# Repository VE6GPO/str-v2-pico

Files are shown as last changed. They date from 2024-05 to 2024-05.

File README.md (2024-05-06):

# Controlling NJW1194 pre-amp with RasPi Pico or Arduino Nano

### NJW1194 has:
- 4 stereo inputs
- SPI interface
- Volume control (separate L/R)
- Tone controls (Bass/Treble)

## Requirements:

### Audio inputs:
- AM Radio
- FM Radio
- IP Radio (Raspberry Pi as an internet radio stream receiver)
- External input (TV)

### MCU inputs - total 12 GPI:
- Power switch - 1 GPI
- Phono/AM/FM switch - 3 GPI
- Tape Select - 1 GPI
- Volume (rotary ctrl) - 2 GPI
- Mute - 1 GPI
- Bass/Treble/Balance - 3 ADC
- IR receiver - 1 GPI

### MCU outputs - total 9 GPO:
- Power relay - 1 GPO
- SPI (Data, Clock, ChipSelect) - 3 GPO
- RGB dial light (PWM) - 3 GPO
- Display I2C - 2 GPO

MCU needs 21 GPIO lines in total, plus maybe another 2 to "talk" to Raspberry Pi ...

### TODO:

- Utilize rotary encoder w. push button for Volume/Mute control
- Use existing pots fed to ADC for controlling Tone + Balance

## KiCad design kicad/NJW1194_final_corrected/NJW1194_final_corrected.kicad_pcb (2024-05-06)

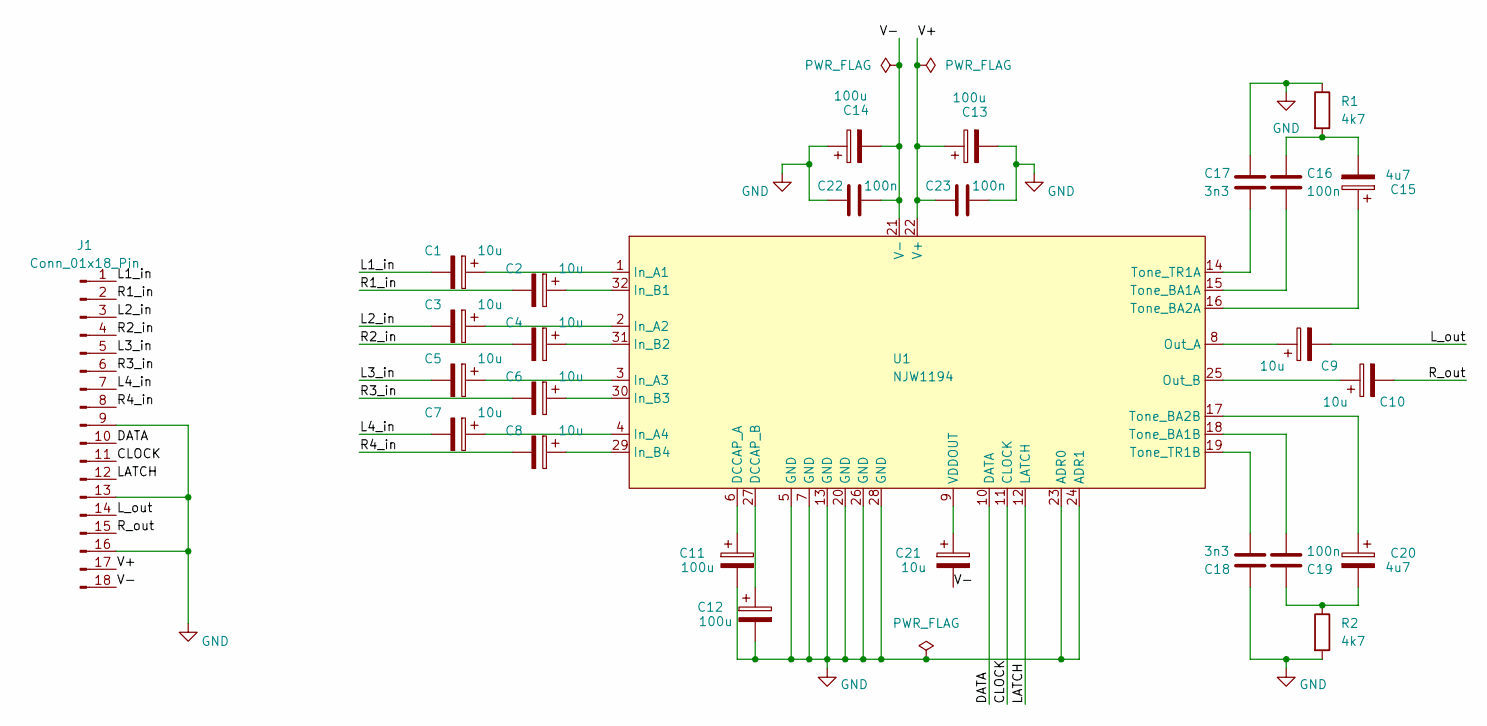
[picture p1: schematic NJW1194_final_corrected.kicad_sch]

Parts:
C1, C2, C3, C4, C5, C6, C7, C8, C9, C10, C21: 10u; CP_Elec_4x5.7
C11, C12, C13, C14: 100u; CP_Elec_6.3x7.7
C15, C20: 4u7; CP_Elec_4x5.7
C16, C19, C22, C23: 100n; C_0805_2012Metric_Pad1.18x1.45mm_HandSolder
C17, C18: 3n3; C_0805_2012Metric_Pad1.18x1.45mm_HandSolder
J1: Conn_01x18_Pin; PinHeader_1x18_P2.54mm_Vertical
R1, R2: 4k7; R_1206_3216Metric_Pad1.30x1.75mm_HandSolder
U1: NJW1194; TSSOP-32_6.1x11mm_P0.65mm

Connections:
/CLOCK: J1.11, U1.11 (CLOCK)
/DATA: J1.10, U1.10 (DATA)
/L1_in: C1.2, J1.1
/L2_in: C3.2, J1.3
/L3_in: C5.2, J1.5
/L4_in: C7.2, J1.7
/LATCH: J1.12, U1.12 (LATCH)
/L_out: C9.2, J1.14
/R1_in: C2.2, J1.2
/R2_in: C4.2, J1.4
/R3_in: C6.2, J1.6
/R4_in: C8.2, J1.8
/R_out: C10.2, J1.15
/V+: C13.1, C23.2, J1.17, U1.22 (V+)
/V-: C14.2, C21.2, C22.1, J1.18, U1.21 (V-)
GND: C11.2, C12.2, C13.2, C14.1, C17.1, C18.1, C22.2, C23.1, J1.9, J1.13, J1.16, R1.1, R2.2, U1.5 (GND), U1.7 (GND), U1.13 (GND), U1.20 (GND), U1.23 (ADR0), U1.24 (ADR1), U1.26 (GND), U1.28 (GND)
unnamed: C15.2, C16.1, R1.2
unnamed: C19.1, C20.2, R2.1
unnamed: C11.1, U1.6 (DCCAP_A)
unnamed: C12.1, U1.27 (DCCAP_B)
unnamed: C1.1, U1.1 (In_A1)
unnamed: C3.1, U1.2 (In_A2)
unnamed: C5.1, U1.3 (In_A3)
unnamed: C7.1, U1.4 (In_A4)
unnamed: C2.1, U1.32 (In_B1)
unnamed: C4.1, U1.31 (In_B2)
unnamed: C6.1, U1.30 (In_B3)
unnamed: C8.1, U1.29 (In_B4)
unnamed: C9.1, U1.8 (Out_A)
unnamed: C10.1, U1.25 (Out_B)
unnamed: C16.2, U1.15 (Tone_BA1A)
unnamed: C19.2, U1.18 (Tone_BA1B)
unnamed: C15.1, U1.16 (Tone_BA2A)
unnamed: C20.1, U1.17 (Tone_BA2B)
unnamed: C17.2, U1.14 (Tone_TR1A)
unnamed: C18.2, U1.19 (Tone_TR1B)
unnamed: C21.1, U1.9 (VDDOUT)

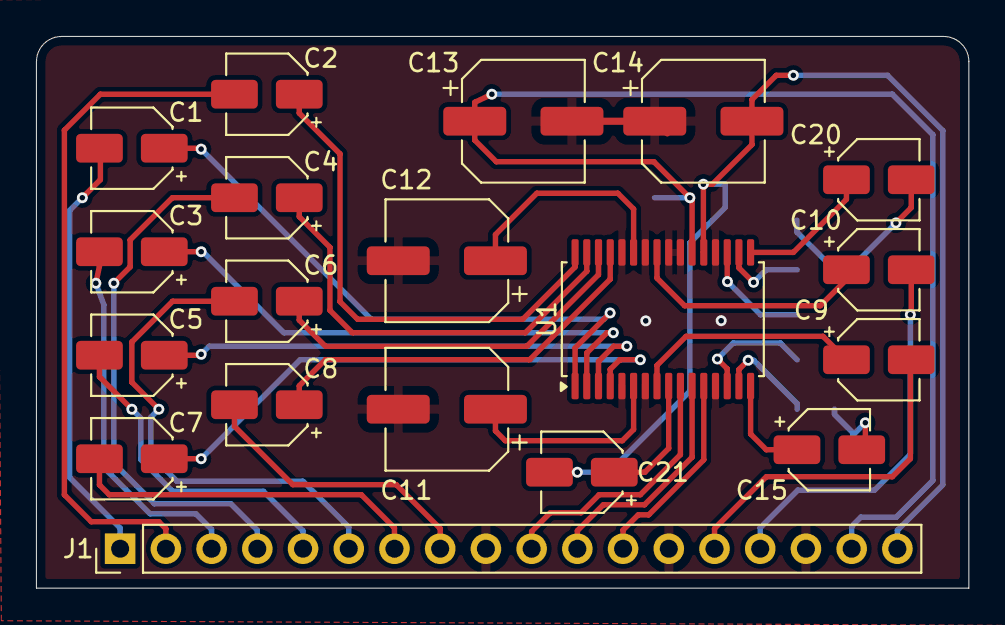
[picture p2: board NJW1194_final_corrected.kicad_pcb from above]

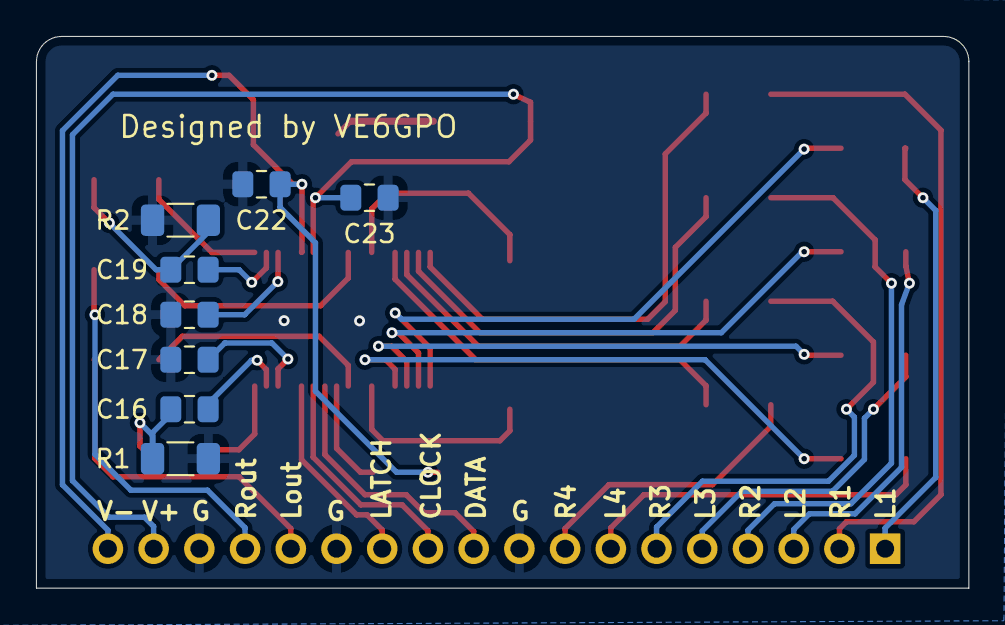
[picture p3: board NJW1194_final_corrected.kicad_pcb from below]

Board: 2 copper layers, 51.8 x 30.6 mm, 27 parts (8 on the bottom side), 37 nets.

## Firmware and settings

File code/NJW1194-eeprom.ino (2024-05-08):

#include <LiquidCrystal_PCF8574.h>
#include <EEPROM.h>
#include <Wire.h>

LiquidCrystal_PCF8574 lcd(0x27); // set the LCD address to 0x27 for a 16 chars and 2 line display

//NANO EEPROM
//each byte hold a value from 0 to 255
#define EEPROM_CHANNEL 0 //1 to 4
#define EEPROM_MUTE 1    //0 or 1
#define EEPROM_VOLUME 2  //1 to 254  <-> 31.5dB to -95dB,default = 64
#define EEPROM_BALANCE 3 //0 to 80   <-> -20dB to 20dB,  default = 40
#define EEPROM_BYPASS 4  //0 or 1
#define EEPROM_TREBLE 5  //0 to 20   <-> -10dB to 10dB,  default = 10
#define EEPROM_BASS 6    //0 to 20   <-> -10dB to 10dB

//NANO GPIO
//pin keys
#define PIN_CHANNEL 9
#define PIN_MUTE 8
#define PIN_UP 7
#define PIN_DOWN 6
#define PIN_SELECT 5 //Volume,Treble,Bass,Balance
#define PIN_BYPASS 4
//pin njw1194
#define PIN_LATCH A1
#define PIN_CLK A2
#define PIN_DATA A3
//pin rotary encoder
#define PIN_CLK2 10
#define PIN_DT 11

//
#define PINBTN(pinname)    \
  pinMode(pinname, INPUT); \
  digitalWrite(pinname, HIGH);

//
#define BTN_EVENT(pinname, pinx, event, longpush)               \
  static boolean lock_##pinname = false;                        \
  static int count_##pinname = 0;                               \
  if (digitalRead(pinx) == LOW && lock_##pinname == false)      \
  {                                                             \
    lock_##pinname = true;                                      \
    count_##pinname = 0;                                        \
    event();                                                    \
    evt_btn_common();                                           \
  }                                                             \
  else if (digitalRead(pinx) == HIGH && lock_##pinname == true) \
  {                                                             \
    lock_##pinname = false;                                     \
  }                                                             \
  else if (digitalRead(pinx) == LOW && longpush)                \
  {                                                             \
    if (count_##pinname < 500)                                  \
      count_##pinname++;                                        \
    else                                                        \
    {                                                           \
      event();                                                  \
      evt_btn_common();                                         \
    }                                                           \
  }

//
struct Config
{
  byte channel, mute, volume, balance, bypass, treble, bass;
};

Config myConfig = {0, 1, 64, 40, 0, 10, 10};

byte select = 0; //0:Vol,1:Tre,2:Bass,3:Bal;

void evt_btn_ch()
{
  myConfig.channel = (myConfig.channel + 1) % 4;
}
void evt_btn_mu()
{
  if (myConfig.mute == 0)
  {
    myConfig.mute = 1;
  }
  else
  {
    myConfig.mute = 0;
  }
}
void evt_btn_vu()
{
  switch (select)
  {
  case 0:
    if (myConfig.volume >= 4 && myConfig.volume <= 32)
      myConfig.volume -= 2; //16 to 31
    if (myConfig.volume >= 33 && myConfig.volume <= 96)
      myConfig.volume--; //-16 to 16  step 0.5db
    if (myConfig.volume >= 98 && myConfig.volume <= 128)
      myConfig.volume -= 2; //-32 to -16 step 1db
    if (myConfig.volume > 128)
      myConfig.volume -= 8;
    break;

  case 1:
    if (myConfig.treble < 20)
      myConfig.treble++;
    break;

  case 2:
    if (myConfig.bass < 20)
      myConfig.bass++;
    break;

  case 3:
    if (myConfig.balance < 80)
      myConfig.balance++;
    break;

  default:
    break;
  }
}
void evt_btn_vd()
{
  switch (select)
  {
  case 0:
    if (myConfig.volume >= 128 && myConfig.volume < 248)
      myConfig.volume += 8;
    if (myConfig.volume >= 96 && myConfig.volume < 128)
      myConfig.volume += 2; //-32 to -16 step 1db
    if (myConfig.volume >= 32 && myConfig.volume < 96)
      myConfig.volume++; //-16 to 16  step 0.5db
    if (myConfig.volume >= 2 && myConfig.volume < 32)
      myConfig.volume += 2; //16 to 31
    break;

  case 1:
    if (myConfig.treble > 0)
      myConfig.treble--;
    break;

  case 2:
    if (myConfig.bass > 0)
      myConfig.bass--;
    break;

  case 3:
    if (myConfig.balance > 0)
      myConfig.balance--;
    break;

  default:
    break;
  }
}
void evt_btn_sl()
{
  select = (select + 1) % 4; //4 modes;
}
void evt_btn_bp()
{
  if (myConfig.bypass == 0)
  {
    myConfig.bypass = 1;
  }
  else
  {
    myConfig.bypass = 0;
  }
}

void evt_btn_common()
{
  //serial print
  Serial.println("==============================");
  Serial.print("Current Select:");
  switch (select)
  {
  case 0:
    Serial.println("VOL");
    break;
  case 1:
    Serial.println("TRE");
    break;
  case 2:
    Serial.println("BAS");
    break;
  case 3:
    Serial.println("BAL");
    break;
  default:
    break;
  }
  Serial.print("Ch: ");
  Serial.print(myConfig.channel);
  Serial.print(", Mute: ");
  Serial.print(myConfig.mute);
  Serial.print(", Vol: ");
  Serial.print((64 - myConfig.volume) / 2.0);
  Serial.println("dB.");
  Serial.print("Bal: ");
  Serial.print((myConfig.balance - 40) / 2.0);
  Serial.println("dB.");
  Serial.print("Bypass: ");
  Serial.print(myConfig.bypass);
  Serial.print(" Treble: ");
  Serial.print((myConfig.treble - 10));
  Serial.print("dB. ");
  Serial.print(" Bass: ");
  Serial.print((myConfig.bass - 10));
  Serial.println("dB. ");

  //lcd print
  lcd.setCursor(2, 0);
  lcd.print(myConfig.channel);
  lcd.setCursor(8, 0);
  lcd.print(myConfig.mute);
  lcd.setCursor(14, 0);
  lcd.print(myConfig.bypass);
  lcd.setCursor(1, 1);
  switch (select)
  {
  case 0:
    lcd.print("VOL :       dB");
    lcd.setCursor(7, 1);
    if ((64 - myConfig.volume) / 2.0 > -16)
    {
      lcd.print((64 - myConfig.volume) / 2.0, 1);
    }
    else
    {
      lcd.print((64 - myConfig.volume) / 2.0, 0);
    }
    break;
  case 1:
    lcd.print("TREB :      dB");
    lcd.setCursor(8, 1);
    lcd.print(myConfig.treble - 10);
    break;
  case 2:
    lcd.print("BASS :      dB");
    lcd.setCursor(8, 1);
    lcd.print(myConfig.bass - 10);
    break;
  case 3:
    lcd.print("BAL :       dB");
    lcd.setCursor(7, 1);
    lcd.print((myConfig.balance - 40) / 2.0, 1);
    break;
  default:
    break;
  }

  //send to njw
  if (myConfig.mute == 0)
  {

    sendVol();
    sendSelect();
    if (myConfig.bypass == 0)
    {
      sendTre();
      sendBass();
    }
    else
    {
      sendBypass();
    }
  }
  else
  {
    sendMute();
  }
}

//encoder type1
void encoderEvent()
{
  byte clkValue = digitalRead(PIN_CLK2); //读取CLK引脚的电平
  byte dtValue = digitalRead(PIN_DT);    //读取DT引脚的电平
  static byte lastCLK = 1;
  if (lastCLK != clkValue)
  {
    lastCLK = clkValue;
    if (clkValue != dtValue)
    {
      evt_btn_vu();
    }
    else
    {
      evt_btn_vd();
    }
    evt_btn_common();
    Serial.print(clkValue != dtValue ? '+' : '-');
  }
}

//encoder type2
void encoderEvent2()
{
  static boolean b = true;               //一个step
  byte clkValue = digitalRead(PIN_CLK2); //读取CLK引脚的电平
  byte dtValue = digitalRead(PIN_DT);    //读取DT引脚的电平
  if (b && clkValue == 0 && dtValue == 1)
  {
    evt_btn_vu();
    b = false;
    Serial.print('+');
  }
  if (b && clkValue == 1 && dtValue == 0)
  {
    evt_btn_vd();
    b = false;
    Serial.print('-');
  }
  if (!b && clkValue == 1 && dtValue == 1)
  {
    b = true;
    evt_btn_common();
  }
}

void updateROM()
{
  EEPROM.update(EEPROM_CHANNEL, myConfig.channel);
  EEPROM.update(EEPROM_MUTE, myConfig.mute);
  EEPROM.update(EEPROM_VOLUME, myConfig.volume);
  EEPROM.update(EEPROM_BALANCE, myConfig.balance);
  EEPROM.update(EEPROM_BYPASS, myConfig.bypass);
  EEPROM.update(EEPROM_TREBLE, myConfig.treble);
  EEPROM.update(EEPROM_BASS, myConfig.bass);

  Serial.println("ROM saved!");
}

void sendRaw(byte data, byte add)
{
  digitalWrite(PIN_LATCH, LOW); //LATCH
  //15-8
  for (byte i = 8; i >= 1; i--)
  {
    digitalWrite(PIN_CLK, HIGH);
    digitalWrite(PIN_DATA, (data >> (i - 1)) % 2);
    Serial.print((data >> (i - 1)) % 2);
    delay(0.01);
    digitalWrite(PIN_CLK, LOW);
    delay(0.01);
  }
  Serial.print("|");
  //7-4
  for (byte i = 4; i >= 1; i--)
  {
    digitalWrite(PIN_CLK, HIGH);
    digitalWrite(PIN_DATA, (add >> (i - 1)) % 2);
    Serial.print((add >> (i - 1)) % 2);
    delay(0.01);
    digitalWrite(PIN_CLK, LOW);
    delay(0.01);
  }
  Serial.print("|");
  //3-0
  for (byte i = 4; i >= 1; i--)
  {
    digitalWrite(PIN_CLK, HIGH);
    digitalWrite(PIN_DATA, LOW);
    Serial.print(0);
    delay(0.01);
    digitalWrite(PIN_CLK, LOW);
    delay(0.01);
  }
  //empty
  digitalWrite(PIN_LATCH, HIGH);
  digitalWrite(PIN_CLK, HIGH);
  digitalWrite(PIN_DATA, LOW);
  delay(0.01);
  Serial.println();
}

void sendVol()
{
  if (myConfig.balance == 40 || myConfig.volume >= 208)
  {
    sendRaw(myConfig.volume, 0);
    sendRaw(myConfig.volume, 1);
  }
  else if (myConfig.balance > 40)
  {
    sendRaw(myConfig.volume + (myConfig.balance - 40), 0);
    sendRaw(myConfig.volume, 1);
  }
  else if (myConfig.balance < 40)
  {
    sendRaw(myConfig.volume, 0);
    sendRaw(myConfig.volume + (40 - myConfig.balance), 1);
  }
}
void sendMute()
{
  sendRaw(255, 0);
  sendRaw(255, 1);
  sendRaw(0, 2);
}
void sendSelect()
{
  sendRaw((myConfig.channel + 1) << 2, 2);
}
void sendTre()
{
  byte tmp = 0;
  if (myConfig.treble > 10)
    tmp = (1 << 7) | ((myConfig.treble - 10) << 3) | 1 << 2;
  else
    tmp = (0 << 7) | ((10 - myConfig.treble) << 3) | 1 << 2;
  sendRaw(tmp, 3);
}
void sendBass()
{
  byte tmp = 0;
  if (myConfig.bass > 10)
    tmp = (1 << 7) | ((myConfig.bass - 10) << 3) | 1 << 2;
  else
    tmp = (0 << 7) | ((10 - myConfig.bass) << 3) | 1 << 2;
  sendRaw(tmp, 4);
}
void sendBypass()
{
  sendRaw(0, 3);
}

void setup()
{
  //serial
  Serial.begin(115200);
  Serial.println("Hello!");
  //lcd
  lcd.begin(16, 2);
  lcd.setBacklight(0);
  lcd.clear();
  delay(500);

  //hello
  lcd.setBacklight(1);
  lcd.home();
  lcd.setCursor(1, 0);
  lcd.print("NJW1194 Volume");
  lcd.setCursor(3, 1);
  lcd.print("Controller");
  delay(500);

  //pin init
  PINBTN(PIN_CHANNEL);
  PINBTN(PIN_MUTE);
  PINBTN(PIN_UP);
  PINBTN(PIN_DOWN);
  PINBTN(PIN_SELECT);
  PINBTN(PIN_BYPASS);
  pinMode(PIN_CLK2, INPUT);
  //digitalWrite(PIN_CLK2, HIGH);
  pinMode(PIN_DT, INPUT);
  //digitalWrite(PIN_DT, HIGH);

  //3-wire njw
  pinMode(PIN_LATCH, OUTPUT);
  digitalWrite(PIN_LATCH, HIGH);
  pinMode(PIN_CLK, OUTPUT);
  digitalWrite(PIN_CLK, HIGH);
  pinMode(PIN_DATA, OUTPUT);
  digitalWrite(PIN_DATA, HIGH);

  if (digitalRead(PIN_CHANNEL) == LOW)
  {
    //reset config
    updateROM();
    Serial.print("RESETED!");
    lcd.clear();
    lcd.setCursor(2, 1);
    lcd.print("RESET CONFIG");
  }
  else
  {
    //load config from eeprom
    myConfig.channel = EEPROM.read(EEPROM_CHANNEL);
    myConfig.mute = EEPROM.read(EEPROM_MUTE);
    myConfig.volume = EEPROM.read(EEPROM_VOLUME);
    myConfig.balance = EEPROM.read(EEPROM_BALANCE);
    myConfig.bypass = EEPROM.read(EEPROM_BYPASS);
    myConfig.treble = EEPROM.read(EEPROM_TREBLE);
    myConfig.bass = EEPROM.read(EEPROM_BASS);
    Serial.println("ROM LOADED!");
    lcd.clear();
    lcd.setCursor(2, 1);
    lcd.print("LOAD CONFIG");
  }
  delay(1000);
  lcd.clear();
  lcd.print("CH  MUTE  PASS");

  evt_btn_common();
}

void loop()
{
  //btn scan
  BTN_EVENT(channel, PIN_CHANNEL, evt_btn_ch, false);
  BTN_EVENT(mute, PIN_MUTE, evt_btn_mu, false);
  BTN_EVENT(up, PIN_UP, evt_btn_vu, true);
  BTN_EVENT(down, PIN_DOWN, evt_btn_vd, true);
  BTN_EVENT(select, PIN_SELECT, evt_btn_sl, false);
  BTN_EVENT(bypass, PIN_BYPASS, evt_btn_bp, false);
  //encoder
  encoderEvent2();

  //save
  delay(1);
  static int count_eeprom = 0;
  count_eeprom++;
  if (count_eeprom == 20000)
  {
    count_eeprom = 0;
    updateROM();
    //save eeprom every 20s
  }
}

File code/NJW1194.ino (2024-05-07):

#include "NJW1194.h"

bool chip_address[4] = {0,0,0,0};

NJW1194 audio_chip;
void setup() {
Serial.begin(9600);
audio_chip.initialize(8,9,10 , chip_address); //audio_chip.initialize(latch_pin ,clock_pin , data_pin , chip_address)
audio_chip.input_selector(1); // value from 0 to 4; 0 for mute
audio_chip.volume_control_1(31); //value from +31.5 to -95; other values mean mute
audio_chip.volume_control_2(31);// value from +31.5 to -95; other values mean mute
audio_chip.treble_control(5); // value from 10 to -10
audio_chip.bass_control(5);// value from 10 to -10
audio_chip.tone_bypass_switch(true); 
}

void loop() {
  // main code here

}

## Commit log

2024-04-18 adds kicad folder and NJW1194 project
    [NJW1194_final.kicad_pcb, NJW1194_final.kicad_sch]
2024-05-06 corrects major mistake on the PCB, wrong IC footprint
    [NJW1194_final.kicad_pcb, NJW1194_final.kicad_sch, NJW1194_final_corrected.kicad_pcb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]
